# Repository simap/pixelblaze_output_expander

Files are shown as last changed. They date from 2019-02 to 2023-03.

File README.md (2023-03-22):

# USE THE APPROPRIATE BRANCH FOR YOUR HARDWARE VERSION!

* v1.x: this branch
* v2.x: https://github.com/simap/pixelblaze_output_expander/tree/v2.x
* v3.x: https://github.com/simap/pixelblaze_output_expander/tree/v3.x

Pixelblaze Output Expander Board
-------------------

This is a UART (serial) driven WS2811/WS2812/WS2813/NeoPixel driver. It receives serial data from another microcontroller at 2Mbps, buffers this data up to 240 RGB or 180 RGBW pixels per channel, handles color ordering, and outputs up to 8 channels with level shifting to 5v.

Its primarily designed as an output expander for [Pixelblaze](https://www.tindie.com/products/12158/), but can be used with any microcontroller that can output 2Mbps serial. It doesn't need to sustain 2Mbps, so this should work even for software serial implementations as long as the microcontroller is capable of outputting single characters at this rate.

See the companion [Arduino Library Driver](https://github.com/simap/pbDriverAdapter/) for use with Arduinos.

Data Frame Format
-------------------

Frames start with a magic 4-byte sequence, followed by the channel ID (8 bits), then the command type (8 bits). Some commands have additional header/structs and payloads, finally every frame is ended with a 32-bit CRC that covers the entire frame (from magic to the last byte before CRC).

```c
typedef struct {
	int8_t magic[4]; //"UPXL"
	uint8_t channel;
	uint8_t recordType; //set channel ws2812 opts+data, draw all
} PBFrameHeader;
```

Two commands are implemented, one sets a channel's configuration and buffer data, and the other draws all channels:

```c
enum {
	SET_CHANNEL_WS2812 = 1, DRAW_ALL
} RecordType;
```

### `SET_CHANNEL_WS2812`

The channel ID is part of the PBFrameHeader. Each board supports 8 channels, and has an additional 3 bits of address configured by cuttable jumpers on the underside of the board. Up to 64 channels can be on the same bus (8 boards w/ 8 channels each).

The `SET_CHANNEL_WS2812` command frame header is immediately followed by a structure defining the configuration for that channel, and then followed by RGB or RGBW pixel data:

```c
typedef struct {
	uint8_t numElements; //0 to disable channel, usually 3 (RGB) or 4 (RGBW)
	uint8_t redIndex :2, greenIndex :2, blueIndex :2, whiteIndex :2; //color orders, data on the line assumed to be RGB or RGBW
	uint16_t pixels;
} PBChannel;
```

In total:

```
PBFrameHeader + PBChannel + bytes[numElements * pixels] + CRC
```

### `DRAW_ALL`

The `DRAW_ALL` command ignores the channel from the frame header, though it must still be followed by a CRC. All channels on the bus are drawn simultaneously when this command is received. This command ignores channel ID.

In total:

```
PBFrameHeader + CRC
```

Error Handling
-------------------

The firmware is designed to tolerate noise and data errors. There isn't enough memory to double-buffer the channel data, but any channel data received is zeroed out in case the CRC does not match.

The magic header provides a way to align frames in case of continuous transmission.

It's assumed that data will be more or less continuously flowing, and the reception code doesn't timeout if the input goes idle.

If part of a frame is received, it will wait for enough data to complete that frame, and eventually throw that out if the CRC doesn't match. If that is in the middle of another frame, it will discard data until the magic frame start sequence is found. 

Timing Considerations
-------------------

There isn't enough memory to double-buffer the channel data, so its possible to send a draw command, and then immediately follow with channel data that will update the buffer as it is being drawn. Usually this is not a problem, but if corrupted data or pixels are very different, it might cause a momentary display glitch until the next frame is drawn.

To avoid any potential issues, you can delay sending the next channel data until drawing is completed. Drawing takes 5760 bit times at 800Khz, or 7.2ms. Given that the input data rate is 2Mbps (and that includes start/stop bits, so effectively 1.6Mbps of data), its possible to delay for less than this as input would be updating buffer area that has already been drawn. Waiting for 3.6ms would give the drawing operation enough of a head start that an `SET_CHANNEL_WS2812` frame won't overtake it. Even if corrupted data is written, it won't get displayed as the CRC mismatch will cause the buffer to be cleared and the channel to be disabled until valid data is sent.

Implementation
-------------------

The implementation is based on [OctoWS2811](https://www.pjrc.com/teensy/td_libs_OctoWS2811.html) and [FadeCandy](https://github.com/scanlime/fadecandy).

Data to be sent out to the LEDs is assembled into bit positions, and then timers and DMA are used to "bit bang" this out on a GPIO port, 8 channels at a time.

TIM1 is set up in slave mode and is gated to TIM3. As long as TIM3 is active, TIM1 is running.

TIM1 has 3 PWM/CC channels set up, each triggers a different DMA channel to fire. 

3 DMA channels are set up:

1. Copies the start bits to the GPIO port. Disabled channels have a 0 for their start bit, so the output remains low, while active channels start a pulse. This is set in circular mode with a length of 1 - basically a "set" command every time this fires.
2. Copies from the data buffer to the GPIO port. This continues the start bit for '1's, or cuts it short for '0's. Disabled channels have all of their data bits zeroed out. DMA transfer length is the number of bytes in the buffer: 5760. Enough for 720 bytes across 8 channels.
3. Copies 8 bits of '1's to the GPIO port reset register, turning off any remaining pulses. This is also set in circular mode with a length of 1.

TIM3 is set up as one long pulse, gating TIM1, and runs for long enough to transmit all of the bits in the buffer.

This all happens with automatic timers and DMA, the CPU doesn't have to do anything once it's set up to start, and the accuracy of the WS2812 signal is very good.

License Information
-------------------
The hardware files are released under [Creative Commons ShareAlike 4.0 International](https://creativecommons.org/licenses/by-sa/4.0/).

Distributed as-is; no warranty is given.

The ElectroMage logo and wizard character is excluded from this license.

The software is released under The MIT License.

The MIT License

Copyright (c) 2018 Ben Hencke

Permission is hereby granted, free of charge, to any person obtaining a copy
of this software and associated documentation files (the "Software"), to deal
in the Software without restriction, including without limitation the rights
to use, copy, modify, merge, publish, distribute, sublicense, and/or sell
copies of the Software, and to permit persons to whom the Software is
furnished to do so, subject to the following conditions:

The above copyright notice and this permission notice shall be included in
all copies or substantial portions of the Software.

THE SOFTWARE IS PROVIDED "AS IS", WITHOUT WARRANTY OF ANY KIND, EXPRESS OR
IMPLIED, INCLUDING BUT NOT LIMITED TO THE WARRANTIES OF MERCHANTABILITY,
FITNESS FOR A PARTICULAR PURPOSE AND NONINFRINGEMENT. IN NO EVENT SHALL THE
AUTHORS OR COPYRIGHT HOLDERS BE LIABLE FOR ANY CLAIM, DAMAGES OR OTHER
LIABILITY, WHETHER IN AN ACTION OF CONTRACT, TORT OR OTHERWISE, ARISING FROM,
OUT OF OR IN CONNECTION WITH THE SOFTWARE OR THE USE OR OTHER DEALINGS IN
THE SOFTWARE.

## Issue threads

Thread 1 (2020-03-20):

WS2801 Support

derwentx, 2020-03-20:
Hey there!
I just purchased one of these boards for experimenting with, was surprised at how inexpensive and simple it was, given my experience in helping build a [similar board](https://drive.google.com/file/d/1d4NM16Z_W12Ip4q4j4QFdFu86iJDR7Xp/view?usp=sharing) , so great job!
I was wondering how feasible it would be to add [WS2801](https://cdn-shop.adafruit.com/datasheets/WS2801.pdf) Support. Once my controller arrives, I'll be able to start playing with the firmware, and might be able to work on a pull request, but I wanted to get your thoughts on this first.

WS2801s have become much more ubiquitous since the SK9822/APA102C patent drama happened a few years ago, and [they are Adafruit's SPI-type IC of choice for LED Strings](https://www.adafruit.com/product/322) so it would certainly open up more possibilities for people to use your chip. I'd be willing to send you some samples if you had the time to work on this. Cheers!

simap, 2020-03-20:
Thanks!

Pixelblaze itself can drive WS2801, and I did consider it for this board. It would need a new frame type, and the latch timing taken into account to prevent overdraw, similar to the ws2812/ws2813 latch. You might be able to share a clock channel with apa102.

Let me know if you need any help getting the project up and running, I'd be happy to assist.

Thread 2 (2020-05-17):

PA9 or PA10 for USART1

cinderblock, 2020-05-17:
Hello,

I'm working on an art piece and we're using your serial -> Pixel expander but with an RS-485 transceiver in front to send the serial data a longer distance.

In designing the board for this, I'm replicating your circuit.

I'm confused about one part of the wiring that I'm hoping you might shed some light on.

In the [schematic](https://github.com/simap/pixelblaze_output_expander/blob/master/hardware/pixelAdapter_f103c8.sch) see that the serial input goes into PA9 (pin 30) on the STM32F103C8T6.

However in the datasheet for the STM32F103C8T6, I see the PA9 is USART1_TX. So is it TX or RX?

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

I was looking for some remapping that might be happening in the code source but didn't see any.

I feel like maybe I'm missing something simple.

simap, 2020-05-18:
It's set for single wire half-duplex mode. In that mode both TX/RX share a pin on pa9. I thought it might be handy in case I wanted to add automatic identification, but never got around to implementing it in firmware.

https://github.com/simap/pixelblaze_output_expander/blob/master/firmware/Core/Src/main.c#L514

cinderblock, 2020-05-18:
Aha! That makes sense. Thank you for the clarification. Knew it was something simple.

We're looking to have bi-directional (full duplex with two differential pairs) communication for these boards. One possible solution would be to just add a separate CPU to do the reverse direction but I suspect there is plenty of headroom available on STM32 to add a couple digital inputs that send their state back.

If I were to develop a Bi-directional protocol for these, would you be curious to see it? We're currently planning a full-duplex protocol but a half-duplex should work too...

simap, 2020-05-18:
of course :)
What are you going to implement with the reverse comms? ID/config? Read memory?

cinderblock, 2020-05-19:
We need to detect a remote button press (which is itself a fancy phantom power digital button) and react to it at the central controller. For wiring reasons, the buttons will be close to some of the lights (and this controller) and I wanted to leverage the existing twisted pairs and GPIO available on this processor. (We briefly considered modifying the code to make a 16-channel expander too, since there are so many open GPIO.)

The project is still in stealth mode. I'm looking forward to getting to tell people about it :D

We hope it can have some of its life at Burning Man but, with how the world is, we'll see how the cookie crumbles.

Closed 2020-05-26.

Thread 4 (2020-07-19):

Programming and Compiling

cinderblock, 2020-07-19:
Hello again.

We have created our first board that replicates your board's features (and adds RS-485, optional half-duplex comms, and GPIO inputs). I am trying to program the board.

It is not clear to me which IDE you are using or how to setup the environment properly. It looks like you might be using some of STM's proprietary tools. I wonder if you could make a quick list of how you program the boards.

On a related note, have you considered using more open tools? I'm thinking something like Platform IO, for instance.

In trying to use common tools that I'm more familiar with, I've got a Segger J-link connected to the MCU. I can `connect` and communicate with the chip over SWD and it reported "success" when I ran `loadbin expanderboard2.bin, 0`. However it's not clear to me if that was the correct way to load the flash. I'm just guessing that the `bin` should be programmed to flash address 0. Any thoughts on this would be greatly appreciated.

I'll have an extra expander to test and compare against on Tuesday but was hoping to get to something working, or at least a better understanding, before then.

Thanks.

simap, 2020-07-20:
Hello!
Yes, I used STM's tools. The `expanderboard2.ioc` file can be used to generate a project with the older STM32CubeMX tool, or in the same tool integrated into Eclipse called STM32CubeIDE.

Once the project and build files are generated, the source files can be dropped in (or otherwise ensure they aren't overwritten by the tool).

If I was doing it from a GH clone, I'd probably do this:
1. Install STM32 Cube IDE
2. Make a new project with the target processor.
3. Replace the template source files and ioc file with that from the GH project.

That would get you a working Eclipse that could flash and debug using SL-link, and should certainly work with Segger J-Link as well.

For programming .bin files, yes, basically you can flash the .bin file to the flash location. I again use ST's tools and an $2 ST-Link clone to do the work. You can see my setup here:

https://www.youtube.com/watch?v=mRDbnhS1aow

I have nothing against PlatformIO, but ST's cube tool is very helpful for setting up all of the clocks and peripheral initialization code. Sometimes I have to rewrite it, but it's usually a good start.

cinderblock, 2020-07-20:
+1 for the fancy proprietary code generators when they work well. I played with Cypress's FPGA/MCU configuration tools in the past. Not sure I could have done it without the GUI.

Is the information in the `ioc` file already included in the source? Should I be able to just use the source and my own build/flashing to make it work? Just curious.

I'll give the STM32 Cube IDE a try. Didn't realize it was based on Eclipse. At least it has that going for it. These days I just want to use VS Code for everything though.

I still don't understand the whole programmer/debugger ecosystem. I have a J-Link but apparently that hardware doesn't cost enough to handle `.elf` and they want an extra subscription to turn that feature on for my hardware. Bleh.

I'm used to the AVR world with `avrdude` and knowing the flash/FUSE layout like the back of my hand. I still haven't used ARM enough I guess. I'll take a look at the clone.

PS, Nice programmer/tester! I did a similar thing for a project. It also gave each one a unique serial number by generating `.hex` files on the fly and only recorded it in the database once it was programmed correctly, all in a nice NodeWeb GUI. :)

PPS, have you seen these? I use them for all my board programming these days. Even some for debugging if needed. https://www.tag-connect.com/product/tc2030-idc-nl

cinderblock, 2020-07-30:
Sorry to bump,

I've got a ST-Link programmer working with STM32CubeProg and am able to load the published `.elf` file onto the chip. However when I send it serial data, the output LED does not turn on. I have tried this with multiple of the boards I have. I'm not seeing why this should work.

My bet is that there are some user configuration bits that need to be set properly but looking through what I've found, I haven't seen anything that seems like it.

Any thoughts would be greatly appreciated.

cinderblock, 2020-07-31:
Wow! I knew it was something stupid simple! Thanks so much for your help.

Turns out my board defaults to `0b111` address while yours is `0b000`!

For those curious, I used [this programmer](https://smile.amazon.com/gp/product/B00PVJ8Q4C) with [STM32CubeProgrammer](https://www.st.com/en/development-tools/stm32cubeprog.html) and the `.elf` file in this repo without a hitch, including updating firmware on the programmer.

simap, 2020-08-06:
@cinderblock
Hey, btw what are you using to send data? There's a lot of folks interested in using these boards with non-Pixelblaze stuff. Are you sending from a Pi or something or from another micro e.g. using code from the [Arduino driver](https://github.com/simap/PBDriverAdapter)? Any code/insights you could share with folks?

cinderblock, 2020-08-07:
For testing I've just hacked an RS-485 transceiver onto a pixelblaze.

High level, the piece will have 3 identical (from an electrical perspective) sculptures. Each sculpture needs 3~4 output expanders to drive the LEDS we want to drive where we want to drive them. So each sculpture will be on a single RS-485 bus carrying a single serial stream of pixel data.

As for driving each sculpture's differential serial line, we have two options:

**Option A**: Lines run to central cabinet with a Windows/Linux machine running our pattern generation software, connected with a USB to RS-485 transceiver.

**Option B**: (If RS-485 runs are too long for baud rate) Lines run to Raspberry Pi based controller at the base of each sculpture and treat/run those as ArtNet/sACN to RS-485 converters.

So, we'll likely be writing our own output drivers. Our main pattern generation software is all in C++ (I think the plan is to release it eventually). I've also written a driver for JavaScript (running from Node.js).

I'm more than happy to share what I have. Where are these discussions?

simap, 2020-08-07:
A lot in this thread:
https://forum.electromage.com/t/new-8x-ws2812-apa102-driver-board/285

and popped up again here:
https://forum.electromage.com/t/pixelblaze-output-expander-raspberry-pi/495/3

cinderblock, 2020-08-11:
Thanks for the links. I don't see what I can contribute to those conversations specifically right now.

I hadn't found these forums. You might consider adding a link to the README ;)

Closed 2020-07-31.

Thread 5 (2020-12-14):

Document APA102 support

simap, 2020-12-14:
Oops, silly me.

simap, 2020-12-14:
For anyone looking:

The source can give you hints here:
https://github.com/simap/pixelblaze_output_expander/blob/master/firmware/Core/Src/app.c#L59

The apa102 data is very similar to WS2812 types.

The apa102 clock frame has a frame header but no payload (like draw). This is needed to clear out the buffer in those bit positions when switching between types on a channel. I usually send all channels every frame, even if clocks don't change.

Frequency is not yet supported, or at least the intention is that it is a hint/request and the controllers may use something else. For example on micros using the DMA driven GPIO these will probably have a single timer driving all ports and wouldn't support per-port frequency settings. I had intended to use the lowest (including ws2812's 800khz of any port is set to it), and future controllers could be better, like an FPGA based one would be free to do per-port frequency.

However, I ran in to limitations with the STM32f103 and disabled the frequency handling code:
https://github.com/simap/pixelblaze_output_expander/blob/master/firmware/Core/Src/app.c#L180

So for now both PB sends 800000Hz and the boards currently hard code that as well, but the protocol bits for frequency still exist.

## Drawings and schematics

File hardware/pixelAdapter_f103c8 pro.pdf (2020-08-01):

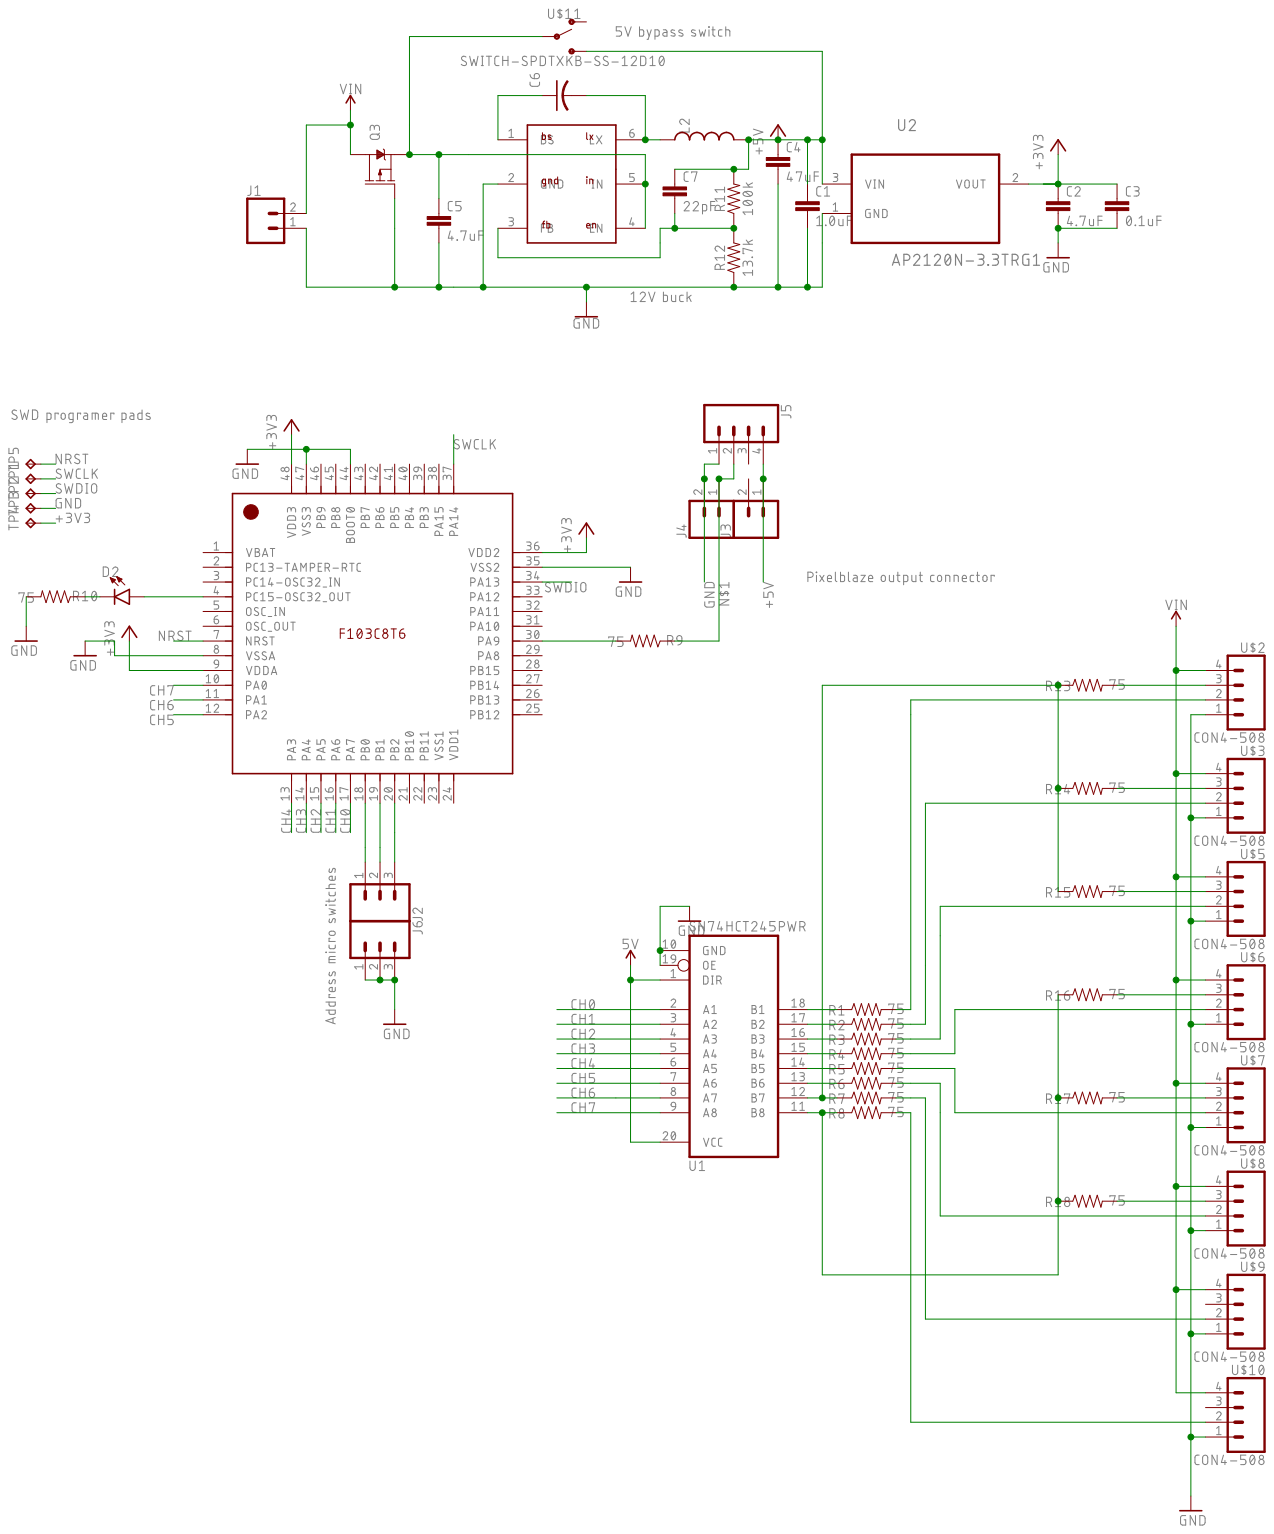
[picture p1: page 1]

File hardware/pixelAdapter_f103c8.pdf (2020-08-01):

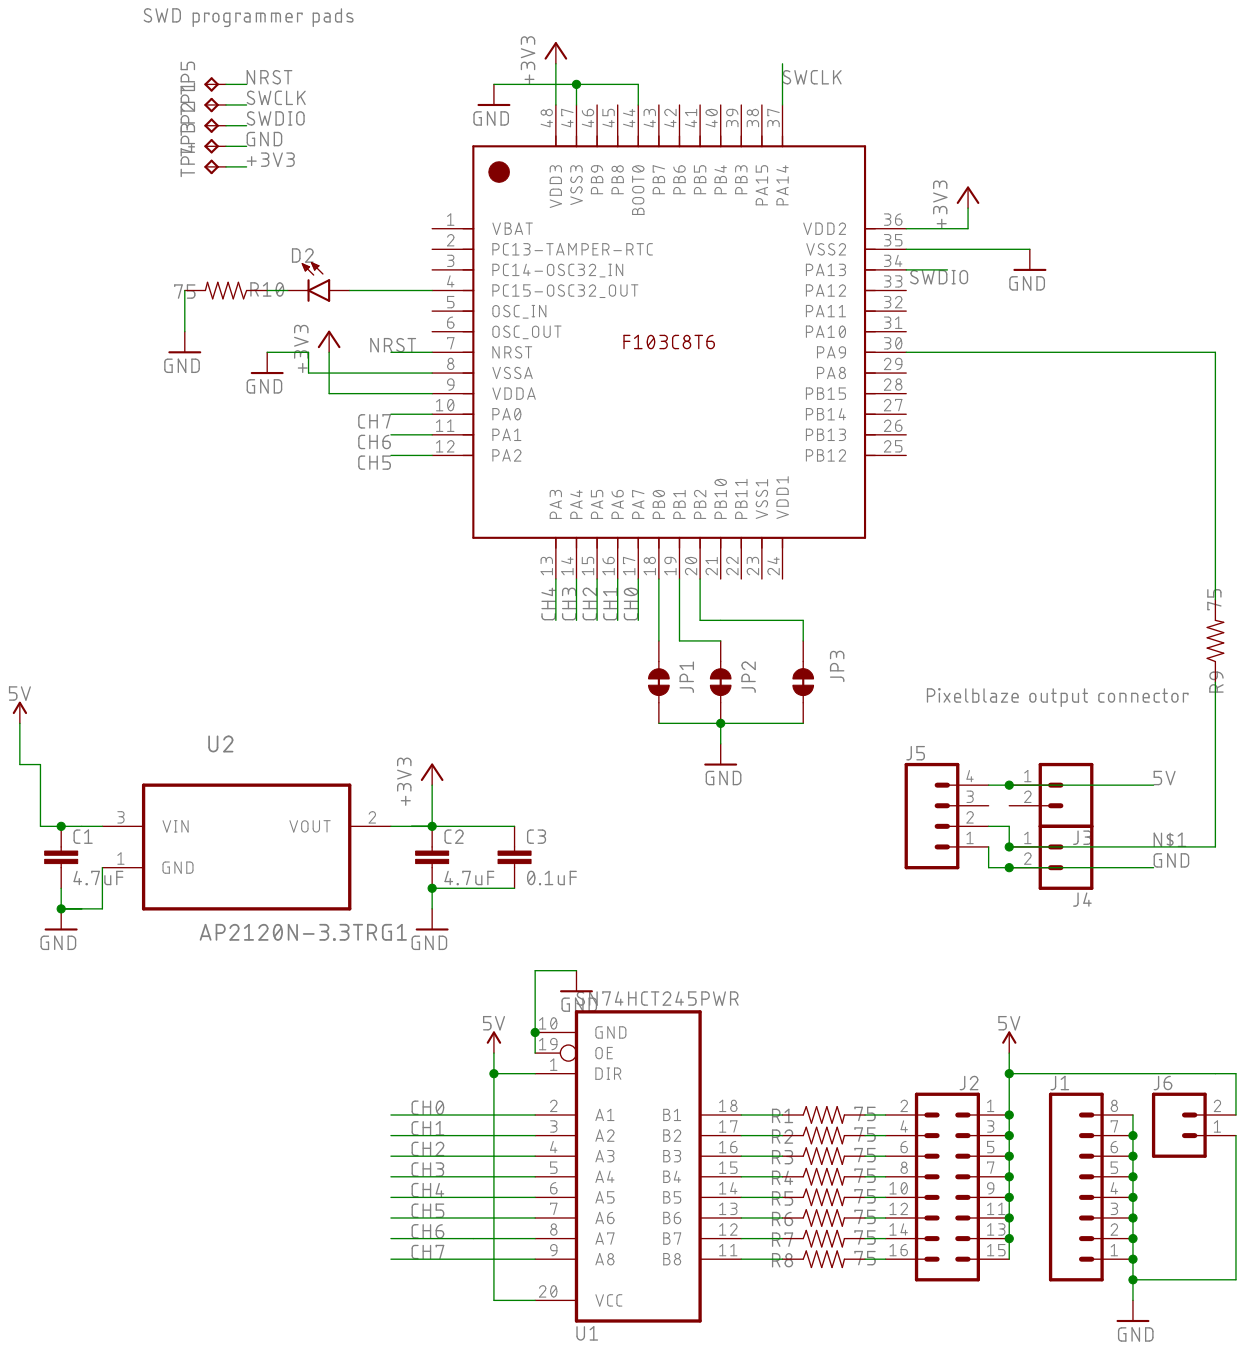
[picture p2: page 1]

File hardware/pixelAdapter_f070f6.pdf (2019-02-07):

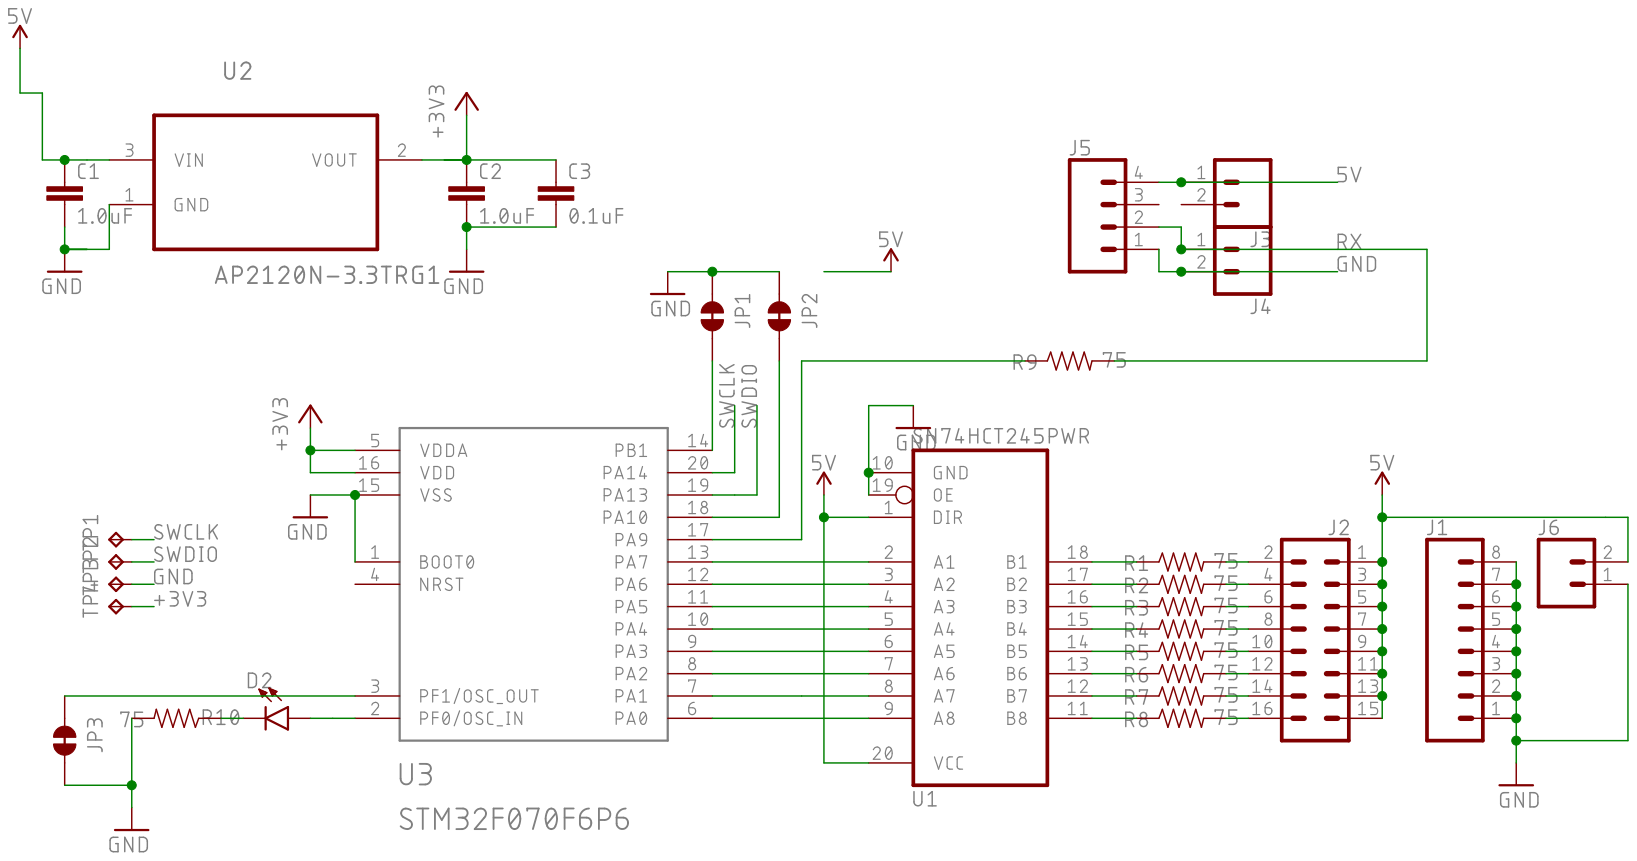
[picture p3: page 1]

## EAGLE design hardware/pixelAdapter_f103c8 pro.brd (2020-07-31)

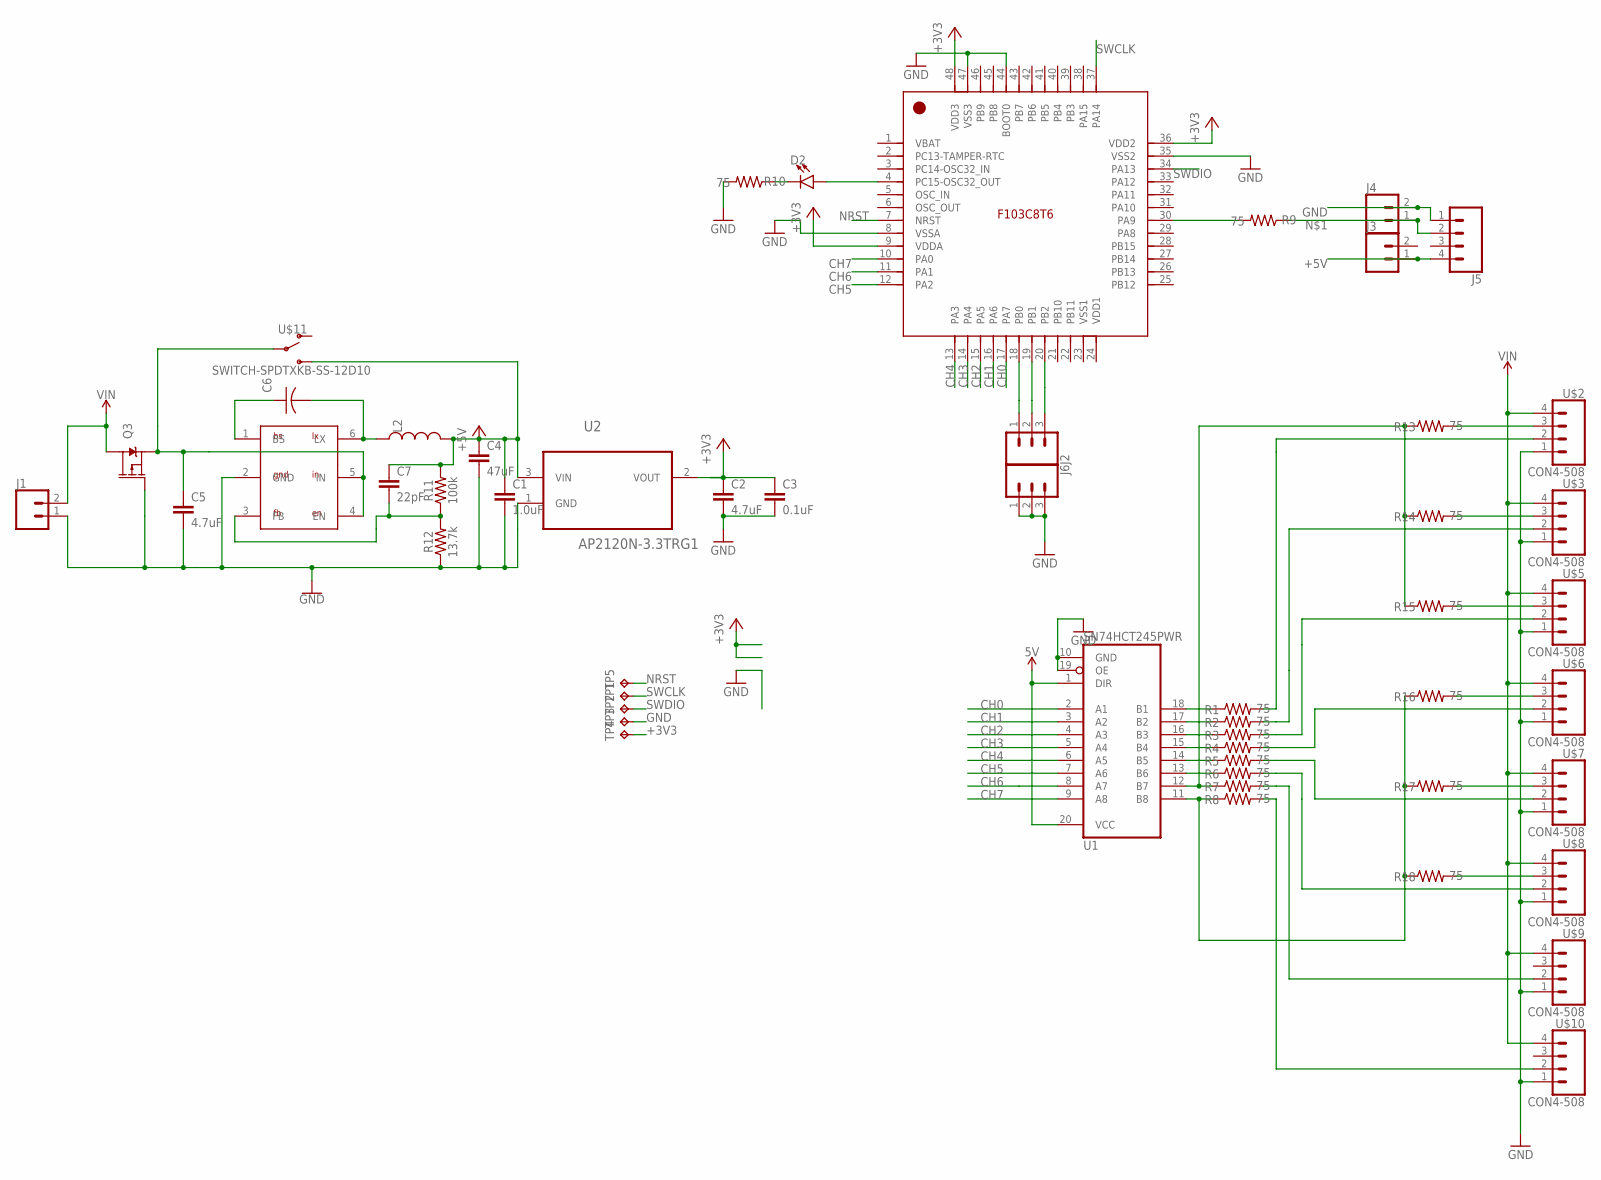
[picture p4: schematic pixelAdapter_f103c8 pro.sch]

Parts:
C1: 1.0uF; 0603
C2: 4.7uF; 0603
C3: 0.1uF; 0603
C4: 47uF; 1206
C5: 4.7uF; 1206
C6: 0.1uF; C0402K
C7: 22pF; 0603
D2: LED0603; LED-0603
J1, J3, J4: CONN_025MM; SCREWTERMINAL-5MM-2
J2, J6: CONN_03LOCK; 1X03_LOCK
J5: CONN_04LOCK; 1X04_LOCK
L2: INDUCTOR3030; INDUCTOR-3030
Q3: 2.5A/30V/105mΩ; SOT23-3
R1, R2, R3, R4, R5, R6, R7, R8, R9, R10, R13, R14, R15, R16, R17, R18: 75; 0603
R11: 100k; 0603
R12: 13.7k; 0603
TP1, TP2, TP3, TP4, TP5: TPTP20SQ; TP20SQ
U1: SN74HCT245PWR; TSSOP20
U2: AP2120N-3.3TRG1; SOT95P237X112-3N
U$1: STM32F103C8T6; LQFP48_7X7MM_0.5MMPP
U$2, U$3, U$5, U$6, U$7, U$8, U$9, U$10: CON4-508
U$4: SY8120B1ABC; SOT23-6
U$11: SWITCH-SPDTXKB-SS-12D10; SWITCH-XKB-SS-12D10

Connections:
+3V3: C2.1, C3.1, TP4.TP, U2.2 (VOUT), U$1.9 (VDDA), U$1.36 (VDD2), U$1.48 (VDD3)
+5V: C1.1, C4.1, C7.1, J3.1, J5.4, L2.P$2 (2), R11.2, U1.1 (DIR), U1.20 (VCC), U2.3 (VIN), U$11.P$3 (S)
ADDR0: J2.1, U$1.18 (PB0)
ADDR1: J2.2, U$1.19 (PB1)
ADDR2: J2.3, U$1.20 (PB2)
CH0: U1.2 (A1), U$1.17 (PA7)
CH1: U1.3 (A2), U$1.16 (PA6)
CH2: U1.4 (A3), U$1.15 (PA5)
CH3: U1.5 (A4), U$1.14 (PA4)
CH4: U1.6 (A5), U$1.13 (PA3)
CH5: U1.7 (A6), U$1.12 (PA2)
CH6: U1.8 (A7), U$1.11 (PA1)
CH7: U1.9 (A8), U$1.10 (PA0)
GND: C1.2, C2.2, C3.2, C4.2, C5.2, J1.1, J4.2, J5.1, J6.1, J6.2, J6.3, Q3.1 (G), R10.2, R12.1, TP3.TP, U1.10 (GND), U1.19 (OE), U2.1 (GND), U$1.8 (VSSA), U$1.35 (VSS2), U$1.44 (BOOT0), U$1.47 (VSS3), U$2.1, U$3.1, U$4.2 (GND), U$5.1, U$6.1, U$7.1, U$8.1, U$9.1, U$10.1
LED0: R1.2, U$2.2
LED1: R2.2, U$3.2
LED2: R3.2, U$5.2
LED3: R4.2, U$6.2
LED4: R5.2, U$7.2
LED5: R6.2, U$8.2
LED6: R7.2, U$9.2
LED7: R8.2, U$10.2
LEDS0: R1.1, U1.18 (B1)
LEDS1: R2.1, U1.17 (B2)
LEDS2: R3.1, U1.16 (B3)
LEDS3: R4.1, U1.15 (B4)
LEDS4: R5.1, U1.14 (B5)
LEDS5: R6.1, U1.13 (B6)
LEDS6: R7.1, R13.1, R14.1, R15.1, U1.12 (B7)
LEDS7: R8.1, R16.1, R17.1, R18.1, U1.11 (B8)
unnamed: J4.1, J5.2, R9.1
unnamed: D2.A, U$1.4 (PC15-OSC32_OUT)
unnamed: R13.2, U$2.3
unnamed: R14.2, U$3.3
unnamed: C6.1, U$4.1 (BS)
unnamed: C6.2, L2.P$1 (1), U$4.6 (LX)
unnamed: C7.2, R11.1, R12.2, U$4.3 (FB)
unnamed: R15.2, U$5.3
unnamed: R16.2, U$6.3
unnamed: D2.C, R10.1
unnamed: R17.2, U$7.3
unnamed: R18.2, U$8.3
NRST: TP5.TP, U$1.7 (NRST)
RX: R9.2, U$1.30 (PA9)
SWCLK: TP1.TP, U$1.37 (PA14)
SWDIO: TP2.TP, U$1.34 (PA13)
VIN: J1.2, Q3.3 (D), U$2.4, U$3.4, U$5.4, U$6.4, U$7.4, U$8.4, U$9.4, U$10.4
VIN1: C5.1, Q3.2 (S), U$4.4 (EN), U$4.5 (IN), U$11.P$2

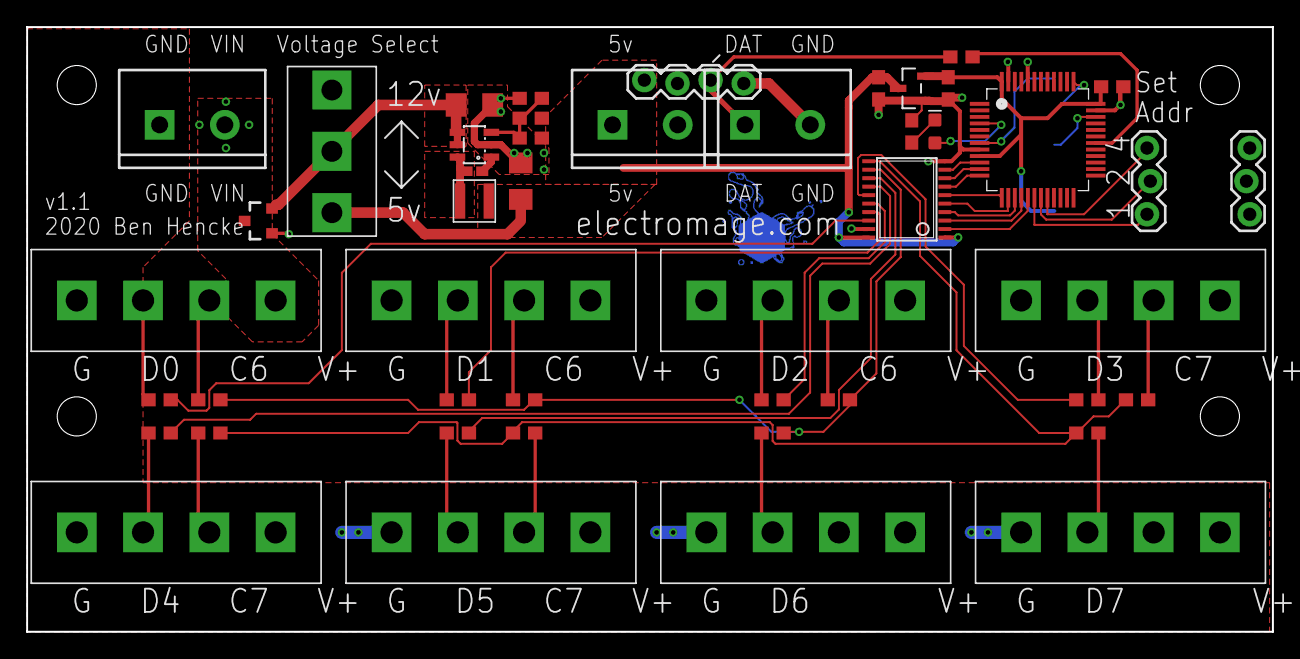
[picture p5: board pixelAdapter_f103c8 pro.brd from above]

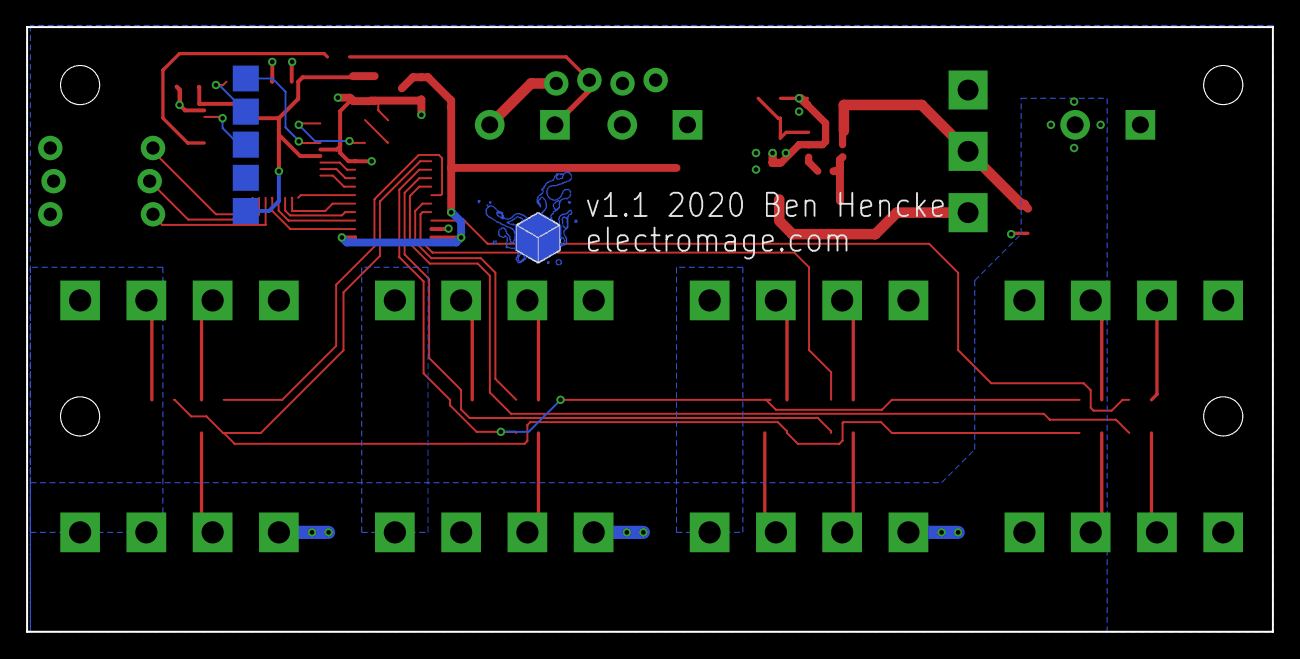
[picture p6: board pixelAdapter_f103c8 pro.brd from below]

Board: 2 copper layers, 95.5 x 46.4 mm, 53 parts (6 on the bottom side), 48 nets.

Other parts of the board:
U$12: ELECTRO_MAGE_PCB4_PIXEL_2#PNG

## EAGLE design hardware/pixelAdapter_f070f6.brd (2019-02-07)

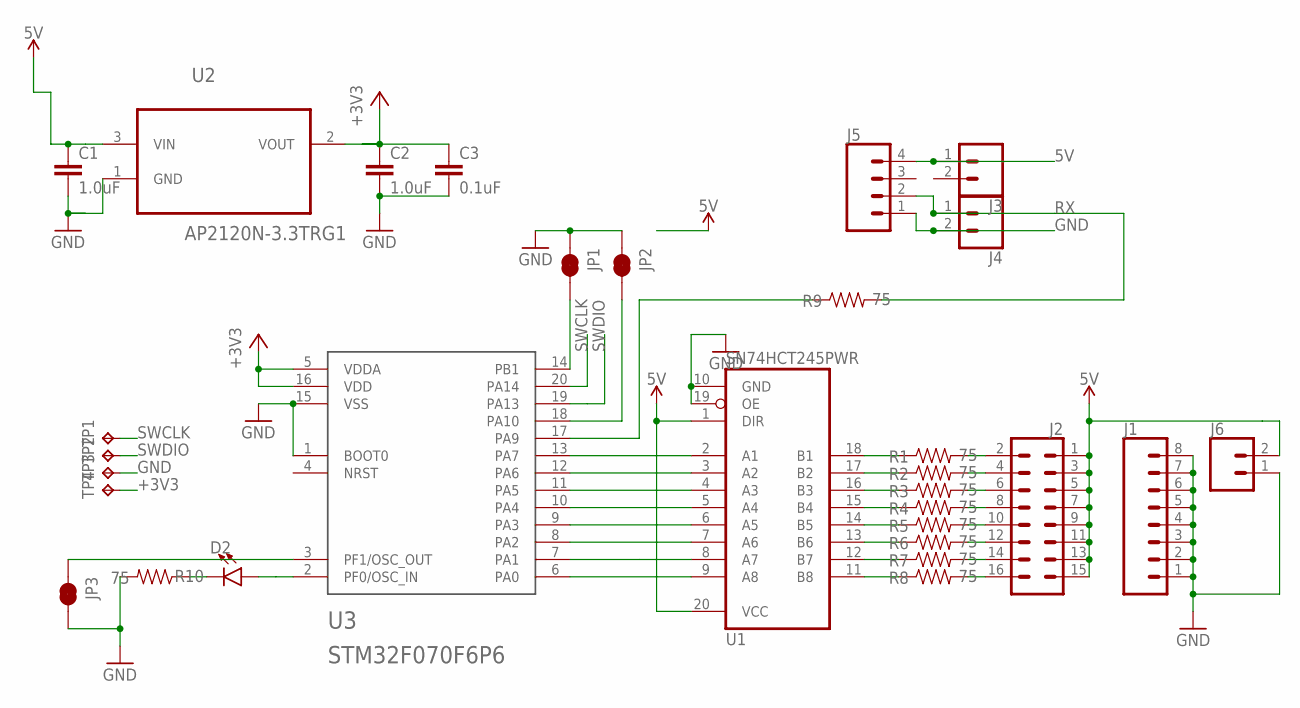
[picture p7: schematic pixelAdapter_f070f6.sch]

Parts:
C1, C2: 1.0uF; 0603
C3: 0.1uF; 0603
D2: LED0603; LED-0603
J1: CONN_08"; 1X08
J2: CONN_08X2; 2X8
J3, J4: CONN_025MM; SCREWTERMINAL-5MM-2
J5: CONN_04LOCK; 1X04_LOCK
J6: CONN_02; 1X02
JP1, JP2, JP3: JUMPER-SMT_2_NC_TRACE_SILK; SMT-JUMPER_2_NC_TRACE_SILK
R1, R2, R3, R4, R5, R6, R7, R8, R9, R10: 75; 0603
TP1, TP2, TP3, TP4: TPTP20SQ; TP20SQ
U1: SN74HCT245PWR; TSSOP20
U2: AP2120N-3.3TRG1; SOT95P237X112-3N
U3: STM32F070F6P6; TSSOP-20

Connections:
5V: C1.1, J2.1, J2.3, J2.5, J2.7, J2.9, J2.11, J2.13, J2.15, J3.1, J5.4, J6.2, U1.1 (DIR), U1.20 (VCC), U2.3 (VIN)
+3V3: C2.1, C3.1, TP4.TP, U2.2 (VOUT), U3.5 (VDDA), U3.16 (VDD)
GND: C1.2, C2.2, C3.2, J1.1, J1.2, J1.3, J1.4, J1.5, J1.6, J1.7, J1.8, J4.2, J5.1, J6.1, JP1.1, JP2.1, JP3.2, R10.2, TP3.TP, U1.10 (GND), U1.19 (OE), U2.1 (GND), U3.1 (BOOT0), U3.15 (VSS)
LED0: J2.2, R1.2
LED1: J2.4, R2.2
LED2: J2.6, R3.2
LED3: J2.8, R4.2
LED4: J2.10, R5.2
LED5: J2.12, R6.2
LED6: J2.14, R7.2
LED7: J2.16, R8.2
unnamed: U1.9 (A8), U3.6 (PA0)
unnamed: JP1.2, U3.14 (PB1)
unnamed: U1.8 (A7), U3.7 (PA1)
unnamed: U1.7 (A6), U3.8 (PA2)
unnamed: U1.2 (A1), U3.13 (PA7)
unnamed: U1.3 (A2), U3.12 (PA6)
unnamed: U1.4 (A3), U3.11 (PA5)
unnamed: U1.5 (A4), U3.10 (PA4)
unnamed: U1.6 (A5), U3.9 (PA3)
unnamed: JP2.2, U3.18 (PA10)
unnamed: JP3.1, U3.3 (PF1/OSC_OUT)
unnamed: R1.1, U1.18 (B1)
unnamed: R2.1, U1.17 (B2)
unnamed: R3.1, U1.16 (B3)
unnamed: R4.1, U1.15 (B4)
unnamed: R5.1, U1.14 (B5)
unnamed: R6.1, U1.13 (B6)
unnamed: R7.1, U1.12 (B7)
unnamed: R8.1, U1.11 (B8)
unnamed: R9.1, U3.17 (PA9)
unnamed: D2.C, R10.1
unnamed: D2.A, U3.2 (PF0/OSC_IN)
RX: J4.1, J5.2, R9.2
SWCLK: TP1.TP, U3.20 (PA14)
SWDIO: TP2.TP, U3.19 (PA13)

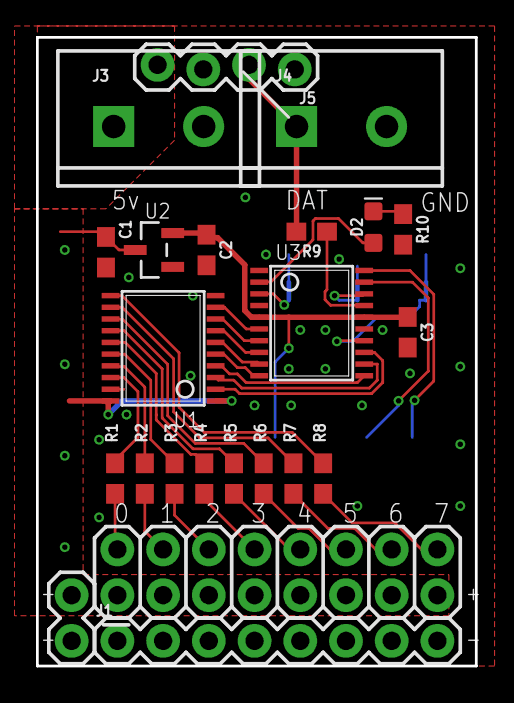
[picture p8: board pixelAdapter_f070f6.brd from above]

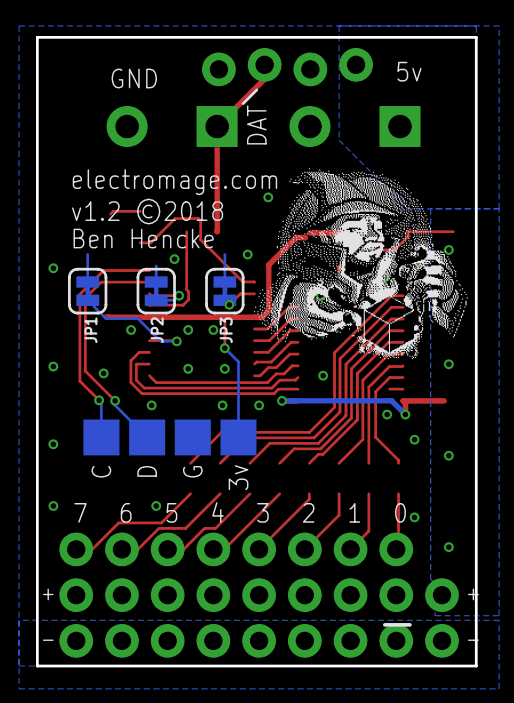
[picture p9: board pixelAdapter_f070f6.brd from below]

Board: 2 copper layers, 24.4 x 34.9 mm, 31 parts (8 on the bottom side), 36 nets.

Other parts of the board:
U$2: EM-LOGO4

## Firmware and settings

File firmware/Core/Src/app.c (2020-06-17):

#include "main.h"
#include "app.h"
#include <string.h>

volatile unsigned long ms;
volatile unsigned long lastDataMs;



//with uart dma, 12 cycles of jitter = 188ns
//with uart dma and cpu w/ nops, 17 cycles. = 265ns
//with uart dma and cpu w/o nops, 20 cycles. = 312ns


//uart -> dma -> circular buffer -> handleIncomming() -> bitBuffer (8 channels) -> dma + timers -> gpio

//microsecond timer on tim4 (prescaler /64)

//tim1 has 3 periods w/ dma triggers to set start bits, data bits from buffer, and clear bits
//tim3 gates tim1 and period should be long enough for data to xfer
//tim3 prescaler matches tim1 period, then number of bytes transfered matches count so they end at the same time

//it would be hard to untangle ws2812 and apa102 as they would be writing to the same port at different times,
//so if both are enabled speed is set at 800khz.
//otherwise, apa102 can set the speed. I want the protocol to support per-channel settings, but the board
//will be limited to one speed. last speed wins? lowest/safest speed?

//for apa102 clock, start bits are cleared, data is zeroed out so when it copies it will toggle clock low (via tim1 data trigger)
//tim2 has a dma trigger to set clocks high (like start bits, but for clocks) half a period (40 cycles) after data is set
//each clock channel needed a bit position anyway.

//apa102 needs a start and end frame, better to write these in memory and not require it in the protocol, borrowing 2 pixels of data


#define BYTES_PER_CHANNEL 2408 //800 RGB or 600 RGBW/HDR, a little extra for apa102 start/end frame
#define BYTES_TOTAL (BYTES_PER_CHANNEL * 8)
uint32_t bitBuffer[BYTES_PER_CHANNEL * 2];


// These vars and data structures are left for reference:
//const static char MAGIC[] = { "UPXL" }; //starts with 0x55, good for auto baud rate detection
// frame headers look like this:
//typedef struct {
//	int8_t magic[4]; //"UPXL"
//	uint8_t channel;
//	uint8_t recordType; //set channel ws2812 opts+data, draw all
//} PBFrameHeader;

enum RecordType {
	SET_CHANNEL_WS2812 = 1, DRAW_ALL, SET_CHANNEL_APA102_DATA, SET_CHANNEL_APA102_CLOCK
};

typedef struct {
	uint8_t numElements; //0 to disable channel, usually 3 (RGB) or 4 (RGBW)
	uint8_t or :2, og :2, ob :2, ow :2; //color orders, data on the line assumed to be RGB or RGBW
	uint16_t pixels;
} PBWS2812Channel;

typedef struct {
	uint32_t frequency;
	uint8_t or :2, og :2, ob :2; //color orders, data on the line assumed to be RGBV (global brightness last)
	uint16_t pixels;
} PBAPA102DataChannel;

typedef struct {
	uint32_t frequency;
} PBAPA102ClockChannel;


typedef struct {
	enum RecordType type;
	union {
		PBWS2812Channel ws2812Channel;
		PBAPA102DataChannel apa102DataChannel;
		PBAPA102ClockChannel apa102ClockChannel;
	};
} PBChannel;

PBChannel channels[8];

//single byte vars for DMA to GPIO
uint8_t ones = 0xff;
//const uint8_t zeros = 0x00;
uint8_t ws2812StartBits = 0;
uint8_t apa102ClockBits = 0;

volatile uint8_t drawingBusy; //set when we start drawing, cleared when dma xfer is complete
//volatile uint32_t lastDrawTimer; //to allow ws2812/13 to latch, set when dma xfer is complete

static inline void ledOn() {
	GPIOC->BSRR |= GPIO_ODR_ODR15;
}
static inline void ledOff() {
	GPIOC->BRR |= GPIO_ODR_ODR15;
}

//some stats for debugging, in a struct to save a few bytes
volatile struct {
	uint16_t crcErrors;
	uint16_t frameMisses;
	uint16_t drawCount;
	uint16_t overDraw;
} debugStats;

//volatile uint8_t ledBrightness;

//3 pins have cuttable jumpers that create an ID on a bus, bits 3-5 of the channel
static inline uint8_t getBusId() {
	uint8_t busId = 0;
	if ((GPIOB->IDR & GPIO_IDR_IDR0))
		busId |= 1;
	if ((GPIOB->IDR & GPIO_IDR_IDR1))
		busId |= 2;
	if ((GPIOB->IDR & GPIO_IDR_IDR2))
		busId |= 4;
	return busId;
}

static inline void startWs2812LatchTimer() {
	TIM4->ARR = 300;
	LL_TIM_EnableCounter(TIM4);
}

static inline int isWs2812LatchTimerRunning() {
	return LL_TIM_IsEnabledCounter(TIM4);
}


static inline void startDrawingChannles() {
	if (drawingBusy) {
		debugStats.overDraw++;
		return;
	}

	//loop through all channels looking for:
	//  * the max bytes any channel wants to send and calculate TIM3 target and update dma xfer CNDTR
	//    otherwise FPS is capped based on theoretical max bytes. was less of a problem when there was 720 bytes
	//  * if any channel is ws2812 and latch time isn't done, then stop now
	//  * set the ws2812StartBits for enabled ws2812 channels
	//  * set the apa102ClockBits for enabled apa102 channels
	//  * find the lowest apa102 frequency
	ws2812StartBits = 0;
	apa102ClockBits = 0;
	int maxBytes = 0;
	int frequency = -1;
	for (int ch = 0; ch < 8; ch++) {
		switch (channels[ch].type) {
		case SET_CHANNEL_WS2812:
			if (channels[ch].ws2812Channel.numElements) {
				if (isWs2812LatchTimerRunning()) {
					debugStats.overDraw++;
					return;
				}
				//don't send start bits for disabled channels
				ws2812StartBits |= 1<<ch;
			}
			int chBytes = channels[ch].ws2812Channel.pixels * channels[ch].ws2812Channel.numElements;
			if (chBytes > maxBytes)
				maxBytes = chBytes;
			break;
		case SET_CHANNEL_APA102_DATA:
			if (channels[ch].apa102DataChannel.frequency) {
				int chBytes = channels[ch].apa102DataChannel.pixels * 4;
				if (chBytes > maxBytes)
					maxBytes = chBytes;
				if (frequency == -1 || channels[ch].apa102DataChannel.frequency < frequency)
					frequency = channels[ch].apa102DataChannel.frequency;
			}
			break;
		case SET_CHANNEL_APA102_CLOCK:
			if (channels[ch].apa102ClockChannel.frequency) {
				apa102ClockBits |= 1<<ch;
				if (frequency == -1 || channels[ch].apa102ClockChannel.frequency < frequency)
					frequency = channels[ch].apa102ClockChannel.frequency;
			}
			break;
		}
	}

//	frequency = 2000000;
//
//	//ws2812 clock overrides anything else
//	if (ws2812StartBits || frequency <= 0) {
		frequency = 800000;
		TIM1->ARR = TIM2->ARR = 79; //64mhz / 800khz = 80
		TIM1->CCR1 = 1; //ws2812 start bits
		TIM1->CCR3 = 16; //triggers data + zeros clocks
		TIM1->CCR4 = 56; //ws2812 stop bits
		TIM2->CCR2 = 57; //sets clock high to latch
//	} else {
//		int reload = (SystemCoreClock / frequency) - 1;
//		if (reload < 4)
//			reload = 4;
//		TIM1->ARR = TIM2->ARR = reload;
//		TIM1->CCR1 = 2; //does this fire?
//		TIM1->CCR3 = 1; //triggers data + zeros clocks
//		TIM1->CCR4 = 3; //does this fire?
//		TIM2->CCR2 = TIM1->ARR>>1; //sets clock high to latch
//	}

	int maxBits = maxBytes *8;

	//all channels have length of zero!
	if (maxBits == 0)
		return;

	debugStats.drawCount++;
	drawingBusy = 1;

	// tim3's prescaler matches tim1's cycle so each increment of tim3 is one bit-time
	TIM3->ARR = maxBits;

	//OK this is a bit weird, there's some kind of pending DMA request that will transfer immediately and shift bits by one
	//set it up to write a zero, then set it up again
	DMA1_Channel6->CCR &= ~DMA_CCR_EN | DMA_CCR_TCIE;
	DMA1_Channel6->CMAR = (uint32_t) &ones;
	DMA1_Channel6->CPAR = (uint32_t) &GPIOA->BRR;
	DMA1_Channel6->CNDTR = 10;
	DMA1_Channel6->CCR |= DMA_CCR_EN;

	//turn it off, set up dma to transfer from bitBuffer
	DMA1_Channel6->CCR &= ~DMA_CCR_EN;
	DMA1_Channel6->CMAR = (uint32_t) &bitBuffer;
	DMA1_Channel6->CPAR = (uint32_t) &GPIOA->ODR;
	DMA1_Channel6->CNDTR = maxBits;
	DMA1->IFCR |= DMA_IFCR_CTCIF3;
	DMA1_Channel6->CCR |= DMA_CCR_EN | DMA_CCR_TCIE;


	TIM1->CNT = 0; //for some reason, tim1 doesnt restart properly unless cleared.
	TIM2->CNT = 0;

	LL_TIM_EnableCounter(TIM1);
	LL_TIM_EnableCounter(TIM3);

//	__WFI();

}

void drawingComplete() {
	drawingBusy = 0; //technically only data xfer is done, but we are still going to clear the last bit when tim1 cc3 fires
	startWs2812LatchTimer();
//	ledOff();
}


//void sysTickIsr() {
//	ms++;
//
//	if (ms - lastDataMs < 1000)
//		ledBrightness = 1;
//	else
//		ledBrightness = 0;
//
//	uint8_t cr = ms & 0x3;
//	if (cr == 0 && ledBrightness) {
//		ledOn();
//	} else if (ledBrightness < cr) {
//		ledOff();
//	}
//}

//anything not already initialized by the generated LL drivers
void setup() {
//	LL_SYSTICK_EnableIT();

	//stop everything when debugging
	DBGMCU->CR = DBGMCU_CR_DBG_IWDG_STOP | DBGMCU_CR_DBG_WWDG_STOP
			| DBGMCU_CR_DBG_TIM1_STOP | DBGMCU_CR_DBG_TIM2_STOP
			| DBGMCU_CR_DBG_TIM3_STOP | DBGMCU_CR_DBG_TIM4_STOP
			| DBGMCU_CR_DBG_CAN1_STOP;


	uartSetup();

	//set up the 4 stages of DMA triggers, spread across tim1 and tim2

	//fires with TIM1_CH1 - set a start bit (if channel is enabled for ws2812)
	DMA1_Channel2->CMAR = (uint32_t) &ws2812StartBits;
	DMA1_Channel2->CPAR = (uint32_t) &GPIOA->BSRR;
	DMA1_Channel2->CNDTR = 1;
	DMA1_Channel2->CCR |= DMA_CCR_EN; // | DMA_CCR_TCIE;

	//fires with TIM1_CH3 - set the data bit (ws2812 data, apa102 data, apa102 clock low
	//for ws2812 this either continues the pulse or turns it into a short one
	//for apa102 data, this is the data bit
	//for apa102 clock, data is zeroed and this will lower the clock pin
	DMA1_Channel6->CMAR = (uint32_t) &bitBuffer;
	DMA1_Channel6->CPAR = (uint32_t) &GPIOA->ODR;
	//enable later
//	DMA1_Channel6->CCR |= DMA_CCR_EN; // | DMA_CCR_TCIE;

	//fires with TIM1_CH4 - clears the ws2812 pulse
	DMA1_Channel4->CMAR = (uint32_t) &ws2812StartBits;
	DMA1_Channel4->CPAR = (uint32_t) &GPIOA->BRR;
	DMA1_Channel4->CNDTR = 1;
	DMA1_Channel4->CCR |= DMA_CCR_EN; // | DMA_CCR_TCIE;

	//fires with TIM2_CH2 - sets the apa102 clock high
	DMA1_Channel7->CMAR = (uint32_t) &apa102ClockBits;
	DMA1_Channel7->CPAR = (uint32_t) &GPIOA->BSRR;
	DMA1_Channel7->CNDTR = 1;
	DMA1_Channel7->CCR |= DMA_CCR_EN; // | DMA_CCR_TCIE;

	//enable the dma xfers on capture compare events
	TIM1->DIER = TIM_DIER_CC1DE | TIM_DIER_CC3DE | TIM_DIER_CC4DE;
	TIM2->DIER = TIM_DIER_CC2DE;

	LL_TIM_EnableMasterSlaveMode(TIM3);

	LL_TIM_EnableCounter(TIM1);
	LL_TIM_EnableCounter(TIM2);

}

// this is the main uart scan function. It ignores data until the magic UPXL string is seen
static inline void handleIncomming() {
	uartResetCrc();
	//look for the 4 byte magic header sequence
	if (uartGetc() == 'U' && uartGetc() == 'P' && uartGetc() == 'X' && uartGetc() == 'L') {
		uint8_t channel = uartGetc();
		uint8_t recordType = uartGetc();
		switch (recordType) {
		case SET_CHANNEL_WS2812: {
			//read in the header
			PBWS2812Channel ch;
			uartRead(&ch, sizeof(PBWS2812Channel));

			if (ch.numElements < 3 || ch.numElements > 4)
				return;
			if (ch.pixels * ch.numElements > BYTES_PER_CHANNEL)
				return;

			//check that it's one of ours
			//TODO handle broadcast?
			if (channel >> 3 != getBusId()) {
				//follow along, but ignore data
				channel = 0xff;
			} else {
				channel = 7 - (channel & 7); //channel outputs are reverse numbered
				ledOn();
			}

			uint8_t or = ch.or;
			uint8_t og = ch.og;
			uint8_t ob = ch.ob;
			uint8_t ow = ch.ow;

			uint8_t elements[4];

			uint32_t * dst = bitBuffer;
			int stride = 2*ch.numElements;
			for (int i = 0; i < ch.pixels; i++) {
				elements[or] = uartGetc();
				elements[og] = uartGetc();
				elements[ob] = uartGetc();
				if (ch.numElements == 4) {
					elements[ow] = uartGetc();
				}
				//this will ignore channel > 7
				bitConverter(dst, channel, elements, ch.numElements);
				dst += stride;
			}

			volatile uint32_t crcExpected = uartGetCrc();
			volatile uint32_t crcRead;
			uartRead((void *) &crcRead, sizeof(crcRead));

			ledOff();
			if (channel < 8) {
				int blocksToZero;
				if (crcExpected == crcRead) {
					if (channels[channel].type == SET_CHANNEL_WS2812
							&& (ch.pixels * ch.numElements >=
									channels[channel].ws2812Channel.pixels * channels[channel].ws2812Channel.numElements)
						) {
						blocksToZero = 0;
					} else {
						//we need to zero out previous data if the data received was less than last time
						blocksToZero = BYTES_PER_CHANNEL - ch.numElements * ch.pixels;
					}

					channels[channel].type = SET_CHANNEL_WS2812;
					channels[channel].ws2812Channel = ch;

					lastDataMs = ms;
				} else {
					//garbage data, disable the channel, zero everything.
					//its better to let the LEDs keep the previous values than draw garbage.
					debugStats.crcErrors++;
					channels[channel].type = SET_CHANNEL_WS2812;
					memset(&channels[channel].ws2812Channel, 0, sizeof(channels[0].ws2812Channel));
					blocksToZero = BYTES_PER_CHANNEL;
				}
				//zero out any remaining data in the buffer for this channel
				if (blocksToZero > 0)
					bitSetZeros(bitBuffer + (BYTES_PER_CHANNEL - blocksToZero)*2, channel, blocksToZero);
			}
			break;
		}
		case DRAW_ALL: {
			uint32_t crcExpected = uartGetCrc();
			uint32_t crcRead;
			uartRead(&crcRead, sizeof(crcRead));
			if (crcExpected == crcRead) {
				startDrawingChannles();
			} else {
				debugStats.crcErrors++;
			}
			break;
		}
		case SET_CHANNEL_APA102_DATA: {
			//read in the header
			PBAPA102DataChannel ch;
			uartRead(&ch, sizeof(ch));
			if (ch.frequency == 0)
				return;
			//make sure we're not getting more data than we can handle
			if ((ch.pixels+2) * 4 > BYTES_PER_CHANNEL)
				return;

			//check that it's one of ours
			//TODO handle broadcast?
			if (channel >> 3 != getBusId()) {
				//follow along, but ignore data
				channel = 0xff;
			} else {
				channel = 7 - (channel & 7); //channel outputs are reverse numbered
				ledOn();
			}

			uint8_t or = ch.or;
			uint8_t og = ch.og;
			uint8_t ob = ch.ob;

			uint8_t elements[4] = {0,0,0,0};
			uint32_t * dst = bitBuffer;

			//start frame
			bitConverter(dst, channel, elements, 4);
			dst += 8;

			for (int i = 0; i < ch.pixels; i++) {
				elements[or+1] = uartGetc();
				elements[og+1] = uartGetc();
				elements[ob+1] = uartGetc();
				elements[0] = uartGetc() | 0xe0;
				bitConverter(dst, channel, elements, 4);
				dst += 8;
			}

			//end frame
			elements[0] = 0xff;
			elements[1] = elements[2] = elements[3] = 0;
			bitConverter(dst, channel, elements, 4);

			volatile uint32_t crcExpected = uartGetCrc();
			volatile uint32_t crcRead;
			uartRead((void *) &crcRead, sizeof(crcRead));

			ledOff();
			if (channel < 8) {
				int blocksToZero;
				if (crcExpected == crcRead) {
					if (channels[channel].type == SET_CHANNEL_APA102_DATA
							&& (ch.pixels >= channels[channel].apa102DataChannel.pixels)
						) {
						blocksToZero = 0;
					} else {
						//we need to zero out previous data if the data received was less than last time
						blocksToZero = BYTES_PER_CHANNEL - ch.pixels * 4;
					}

					channels[channel].type = SET_CHANNEL_APA102_DATA;
					channels[channel].apa102DataChannel = ch;

					lastDataMs = ms;
				} else {
					//garbage data, disable the channel, zero everything.
					//its better to let the LEDs keep the previous values than draw garbage.
					debugStats.crcErrors++;
					channels[channel].type = SET_CHANNEL_APA102_DATA;
					memset(&channels[channel].apa102DataChannel, 0, sizeof(channels[0].apa102DataChannel));
					blocksToZero = BYTES_PER_CHANNEL;
				}
				//zero out any remaining data in the buffer for this channel
				//TODO FIXME apa102 zeros will cause a start frame, not what we want. set to all ones instead
				if (blocksToZero > 0)
					bitSetZeros(bitBuffer + (BYTES_PER_CHANNEL - blocksToZero)*2, channel, blocksToZero);
			}
			break;
		}
		case SET_CHANNEL_APA102_CLOCK: {
			//read in the header
			PBAPA102ClockChannel ch;
			uartRead(&ch, sizeof(ch));
			if (ch.frequency == 0)
				return;

			//check that it's one of ours
			//TODO handle broadcast?
			if (channel >> 3 != getBusId()) {
				//follow along, but ignore data
				channel = 0xff;
			} else {
				channel = 7 - (channel & 7); //channel outputs are reverse numbered
				ledOn();
			}

			volatile uint32_t crcExpected = uartGetCrc();
			volatile uint32_t crcRead;
			uartRead((void *) &crcRead, sizeof(crcRead));

			ledOff();
			if (channel < 8) {
				int blocksToZero;
				if (crcExpected == crcRead) {
					if (channels[channel].type == SET_CHANNEL_APA102_CLOCK) {
						blocksToZero = 0;
					} else {
						//we need to zero out previous data
						blocksToZero = BYTES_PER_CHANNEL;
					}

					channels[channel].type = SET_CHANNEL_APA102_CLOCK;
					channels[channel].apa102ClockChannel = ch;

					lastDataMs = ms;
				} else {
					//garbage data, disable the channel, zero everything. Some apa102 channels could be without clock, so should remain unchanged
					debugStats.crcErrors++;
					channels[channel].type = SET_CHANNEL_APA102_CLOCK;
					memset(&channels[channel].apa102ClockChannel, 0, sizeof(channels[0].apa102ClockChannel));
					blocksToZero = BYTES_PER_CHANNEL;
				}
				//zero out any remaining data in the buffer for this channel
				if (blocksToZero > 0)
					bitSetZeros(bitBuffer + (BYTES_PER_CHANNEL - blocksToZero)*2, channel, blocksToZero);
			}
			break;
		}
		default:
			break;
			//unsupported op or garbage frame, just wait for the next one
		}

	} else {
		debugStats.frameMisses++;
	}
}
void loop() {
	for (;;) {
		if (uartAvailable() > 0) {
			handleIncomming();
		}
	}
}

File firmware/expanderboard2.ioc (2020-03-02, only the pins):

Mcu.UserName=STM32F103C8Tx
PA0-WKUP.Signal=GPIO_Output
PA1.Signal=GPIO_Output
PA13.Signal=SYS_JTMS-SWDIO
PA14.Signal=SYS_JTCK-SWCLK
PA2.Signal=GPIO_Output
PA3.Signal=GPIO_Output
PA4.Signal=GPIO_Output
PA5.Signal=GPIO_Output
PA6.Signal=GPIO_Output
PA7.Signal=GPIO_Output
PA9.Signal=USART1_TX
PB0.Signal=GPIO_Input
PB1.Signal=GPIO_Input
PB2.Signal=GPIO_Input
PC15-OSC32_OUT.Signal=GPIO_Output

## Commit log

2018-11-15 initial, working ish
    need to swap tim1 and tim2, but its working
    dma driving ws2812 via timers and tricks
    [pixelblaze_io_board Debug.cfg]
2018-11-25 working, adding timeout and reset autobaud
    [app.c, uart.c]
2018-11-27 WIP switch chipsets, need to move tim2 to tim3
2018-11-29 working, but still a few small dma glitches
    [app.c]
2018-11-29 fix dma glitch
2018-12-16 fix bitconverter, dma glitch
    [app.c, uart.c]
2018-12-17 swap channel order to match hw
    [app.c]
2019-02-07 hardware files
    [pixelAdapter_f070f6.brd, pixelAdapter_f070f6.sch]
2019-02-07 schematic pdf
2019-12-19 stm32f103 variant
    [pixelAdapter_f103c8.brd, pixelAdapter_f103c8.sch]
2019-12-19 port to stm32f103 and use new cube ide
    also rename directory to firmware
    [expanderboard2 Debug.cfg, pixelblaze_io_board Debug.cfg]
2020-02-17 working w/ both 2812 and apa102
    [expanderboard2 Debug.cfg]
2020-03-02 dma latency issues, add some nops, lessen interrupts. WIP
    [app.c]
2020-03-02 remove all timer interrupts, use a one shot for ws2812 latch
    also for some reason, nops in bit converter code dont
2020-06-14 Replaced wrong "UPLX" magic string in comment with "UPXL"
    [app.c]
2020-07-31 pro boards v1.1
    [pixelAdapter_f103c8 pro.brd, pixelAdapter_f103c8 pro.sch]
2020-07-31 remove some unused symbols
    [pixelAdapter_f103c8 pro.sch]
2020-07-31 remove unused symbols
    [pixelAdapter_f103c8.sch]
2020-08-01 clean up schematics a little, get pdfs
    [pixelAdapter_f103c8 pro.sch, pixelAdapter_f103c8.sch]

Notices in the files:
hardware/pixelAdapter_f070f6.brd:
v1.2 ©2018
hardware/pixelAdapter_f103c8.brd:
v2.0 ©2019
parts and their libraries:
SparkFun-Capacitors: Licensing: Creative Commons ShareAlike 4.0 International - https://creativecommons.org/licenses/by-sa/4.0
